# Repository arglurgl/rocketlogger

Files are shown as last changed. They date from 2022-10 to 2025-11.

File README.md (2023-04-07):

# rocketlogger
A data logger for water rockets

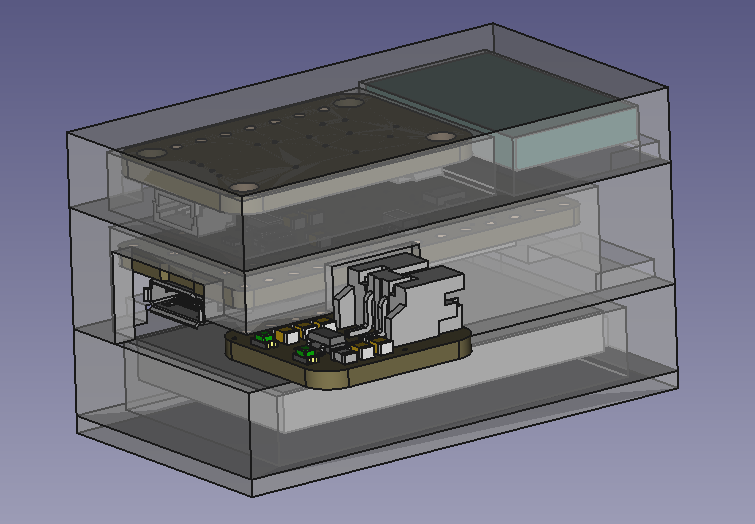
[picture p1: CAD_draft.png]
Draft Version


## Hardware
* Adafruit 4481 ItsyBitsy NRF52840
* Adafruit 2652 BMP280 STEMMA QT Altimeter and Pressure
* Generic Bosch BNO055 Acceleration and Attitude Breakout Board
* Adafruit 2124 LiPo Charger Backpack
* Generic 150 mAh LiPo Battery

## Planned Features
* Log altitude, acceleration, heading, ...
* Transfer data after landing via Bluetooth
* Data viewer with derived values like climb speed etc.
* Trigger parachute deployment
* Rocket recovery helper via sound and light
* (Speed logging from ground via audio (Doppler) and light (flashing and long exposure at night)

## First Time Setup
When running the code for the first time on a new board it will complain in the serial monitor about the filesystem missing. To format the flash, simply uncomment the line `format_flash();` in `setup()` and hit 'upload and monitor' in PlatformIO. Confirm the format in the serial monitor, and when done comment the format_flash line out again and re-upload the code to restart the board.

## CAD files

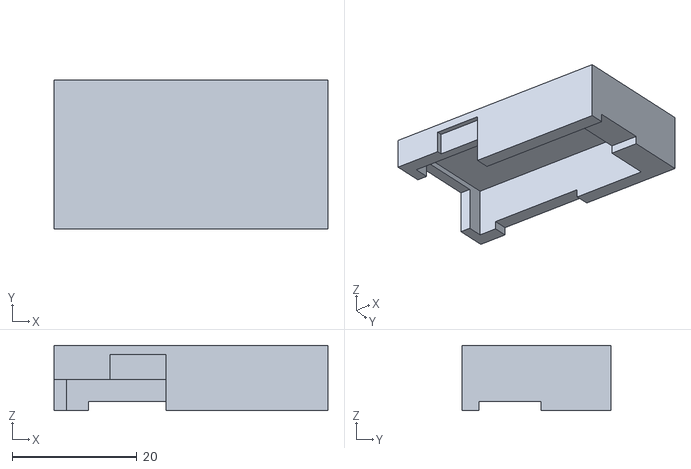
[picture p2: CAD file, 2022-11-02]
CAD/mainComp.stl
44.0 x 24.0 x 10.5

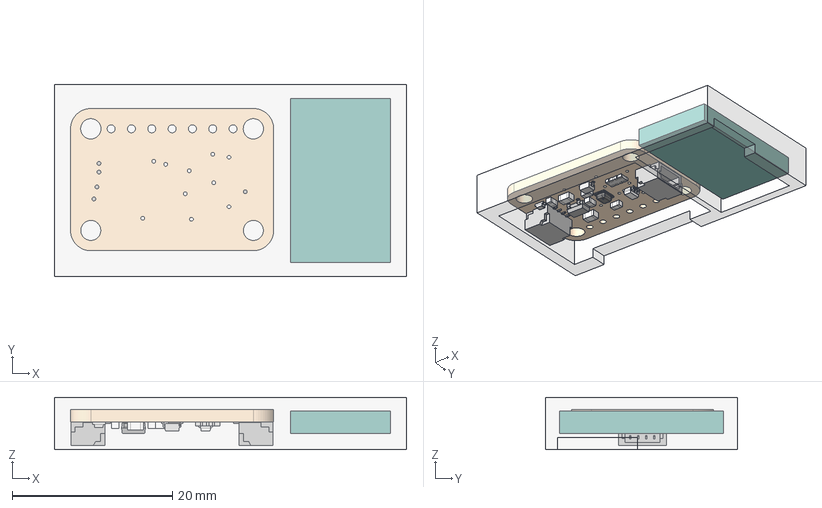
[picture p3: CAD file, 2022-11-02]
CAD/assembly.FCStd
44.0 x 24.0 x 6.50 mm
Board002
0805-NO008
0805-NO009
SOT23-007
0603-NO006
0603-NO007
0603-NO008
0603-NO009
RESPACK_4X0603
SOT363
JST_SH4
JST_SH005
CHIPLED_0603_NOOUTLINE
SOD-323
BMX280_COMBO
BNO055
alti+accel

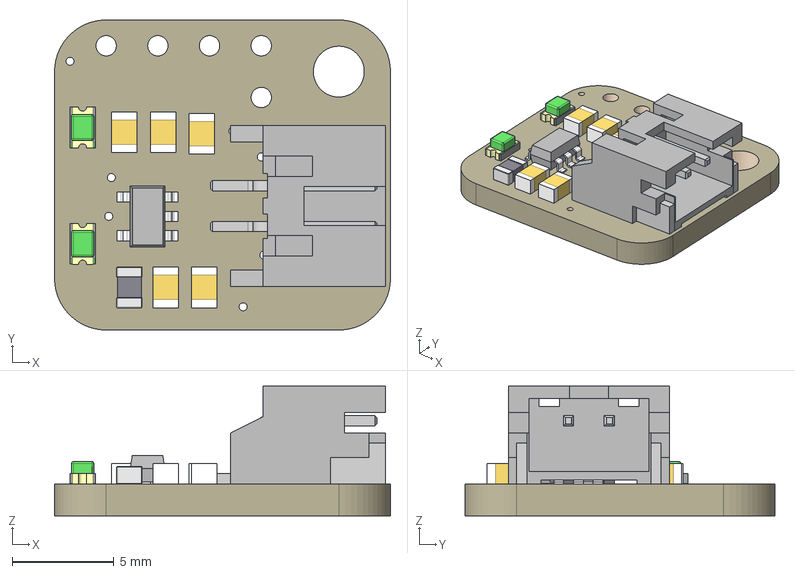
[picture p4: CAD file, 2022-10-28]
CAD/adafruit models/2124 Trinket Lipo Backpack.step
16.5 x 15.2 x 6.37 mm
Board
MCP73831T-2ACI/OT
GREEN x 2
2.5K x 5
JSTPH
10K\

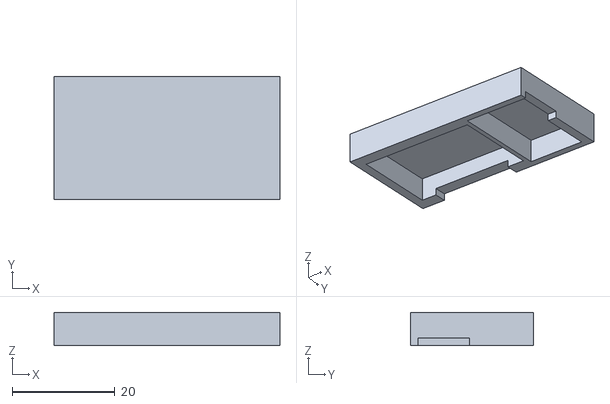
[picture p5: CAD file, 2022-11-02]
CAD/sensorComp.stl
44.0 x 24.0 x 6.50

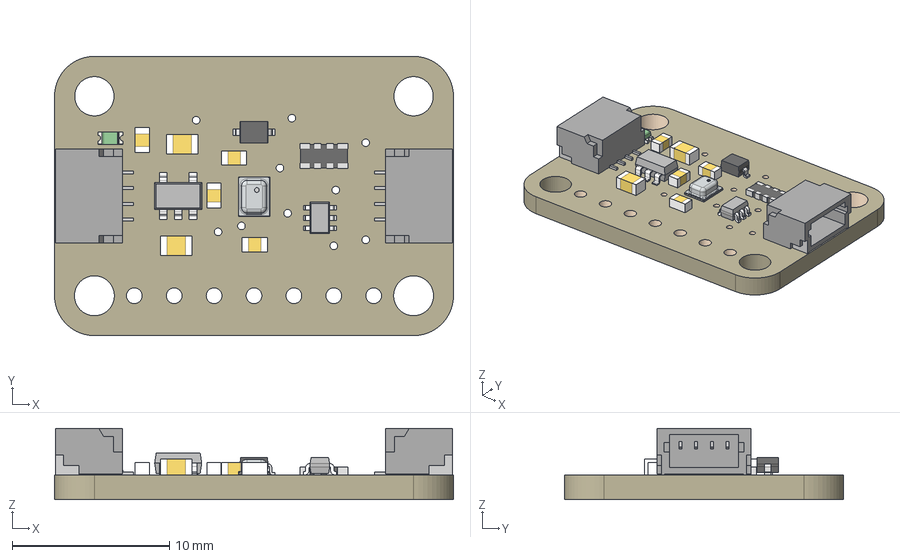
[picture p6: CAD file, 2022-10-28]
CAD/adafruit models/2652 BMP280 STEMMA QT.step
25.4 x 17.8 x 4.53 mm
Board
10uF x 2
AP2112K-3.3
10K x 4
10K_1
BSS138
STEMMA_I2C_QT x 2
GREEN
1N4148
BMX280_COMBO

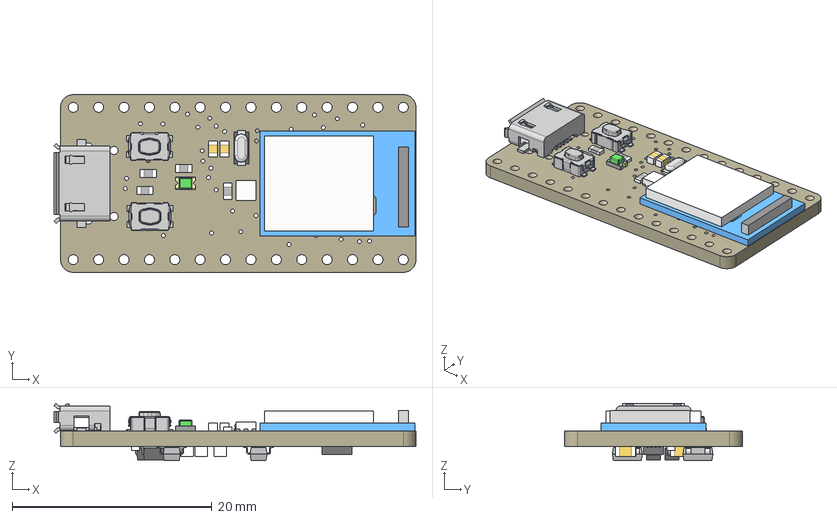
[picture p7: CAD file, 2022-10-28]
CAD/adafruit models/4481 ItsyBitsy nRF52840.step
36.2 x 17.8 x 5.74 mm
Board
KMR2 x 2
AP2112(3.3V)
4u20329
MBR120 x 2
RED
MDBT50
GD25Q16
10K x 6
10uF x 3
AP102-2020
22pF x 2
74HCT1G125DBV

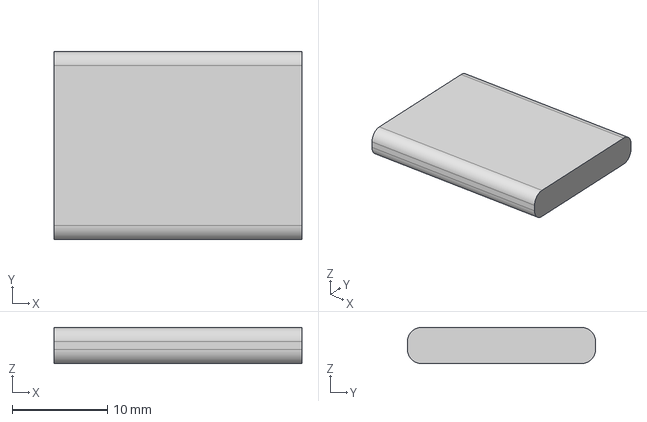
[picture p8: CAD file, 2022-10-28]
CAD/adafruit models/1317 150mAh Lipo Battery.step
26.0 x 19.8 x 3.80 mm

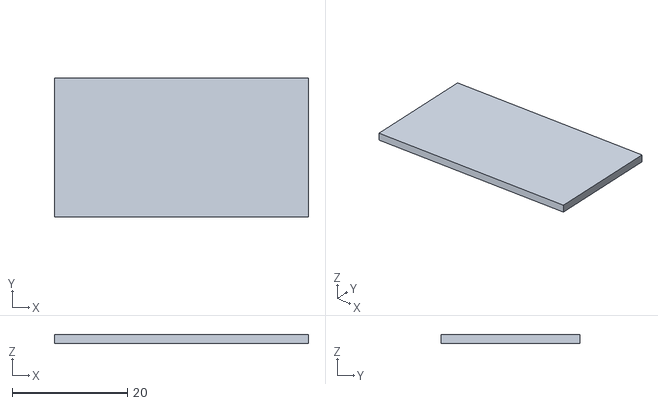
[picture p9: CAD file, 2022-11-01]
CAD/cover.stl
44.0 x 24.0 x 1.50

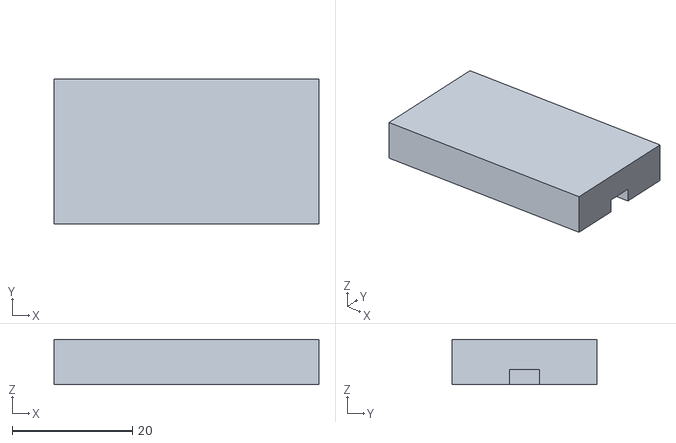
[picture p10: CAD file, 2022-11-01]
CAD/batteryComp.stl
44.0 x 24.0 x 7.50

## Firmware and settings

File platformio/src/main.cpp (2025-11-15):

/*********************************************************************
 This is an example for our nRF52 based Bluefruit LE modules

 Pick one up today in the adafruit shop!

 Adafruit invests time and resources providing this open source code,
 please support Adafruit and open-source hardware by purchasing
 products from Adafruit!

 MIT license, check LICENSE for more information
 All text above, and the splash screen below must be included in
 any redistribution
*********************************************************************/
#include <Arduino.h>
#include <SPI.h>
#include <Adafruit_Sensor.h>
#include <utility/imumaths.h>
#include <flash.h>
#include <bluetooth.h>
#include <pressure.h>
#include <orientation.h>
#include <led.h>
#include <flightstate.h>

#define INITIAL_REF_HEIGHT 50.0 // height to use in initial setup //TODO save in persistent memory

// New: flight logging / state machine constants and storage
#define MAX_SAMPLES 12000
#define SAMPLE_INTERVAL_MS 100        
#define LAUNCH_DELTA 1.0             // meters above armed reference to detect launch
#define LAND_ALT_THRESHOLD 0.3       // meters to consider landed
#define MIN_RECORD_TIME_MS 2000      // min recording time before landing is recognized

static FlightState flightState = STANDBY;

static size_t log_count = 0;
static unsigned long lastSampleMillis = 0;
static unsigned long recordingStartMillis = 0;
static float armed_ref_height = 0.0f;

// BLE packet buffer
//    READ_BUFSIZE            Size of the read buffer for incoming packets
#define READ_BUFSIZE                    (20)
uint8_t packetbuffer_receive[READ_BUFSIZE+1];

// Function prototypes
uint8_t readPacket(BLEUart *ble_uart, uint16_t timeout);
void startArming();
void startRecording();
void stopRecording();
void sampleIfNeeded();
void transferLog();
// New prototype for status send
void sendStatusViaBLE(BLEUart *bleuart);

// New: helper to parse remote_logger packets (expected: 0x00, 'T', sub)
static bool handleRemoteCommand(uint8_t *pkt, uint8_t len)
{
  if (len < 3) return false; // need at least 3 bytes
  // remote_logger sends: [0]=0x00, [1]='T', [2]=sub
  // be tolerant: require pkt[1]=='T'
  if (pkt[1] != 'T') return false;

  char sub = pkt[2];
  if (sub == 'A') // Arm
  {
    if (flightState == STANDBY)
      startArming();
    else
      Serial.println("Cannot arm: not in STANDBY");
  }
  else if (sub == 'T') // Transfer
  {
    if (flightState == STANDBY)
      transferLog();
    else
      Serial.println("Cannot transfer: must be in STANDBY");
  }
  else if (sub == 'S') // Stop / abort
  {
    stopRecording();
  }
  else if (sub == 'I') // Info / Status
  {
    // always allowed; send current state and sample count
    sendStatusViaBLE(&bleuart);
  }
  else
  {
    Serial.print("Unknown remote subcommand: ");
    Serial.println(sub);
    return false;
  }
  return true;
}

// Packet buffer
extern uint8_t packetbuffer_receive[];

// for testing BLE data stream
bool ble_stream = false;

void printBMP280Values()
{
  Serial.print(F("Temperature = "));
  Serial.print(pressureSensor.readTemperature());
  Serial.println(" *C");

  Serial.print(F("Pressure = "));
  Serial.print(pressureSensor.readPressure());
  Serial.println(" Pa");

  Serial.print(F("appr. relative height = "));
  float rel_height = relativeAltitude();
  Serial.print(rel_height, 1); /* Adjusted to local forecast! */
  Serial.println(" m");

  // LED for speed test
  if (rel_height > 0)
    rgbled.setPixelColor(0, 0, 64, 0);
  else
    rgbled.setPixelColor(0, 64, 0, 0);
  rgbled.show();

  Serial.println();
}

void sendSensorValues()
{
  sensors_event_t event;

  // get the sensor data
  orientationSensor.getEvent(&event, Adafruit_BNO055::VECTOR_GRAVITY);
  float temp = pressureSensor.readTemperature();
  float press = pressureSensor.readPressure();
  float rel_height = relativeAltitude();

  Serial.print("Gravity ");
  Serial.print("X: ");
  Serial.print(event.acceleration.x, 4);
  Serial.print("\tY: ");
  Serial.print(event.acceleration.y, 4);
  Serial.print("\tZ: ");
  Serial.print(event.acceleration.z, 4);
  Serial.println("");

  Serial.print(F("Temperature = "));
  Serial.print(temp);
  Serial.println(" *C");

  Serial.print(F("Pressure = "));
  Serial.print(press);
  Serial.println(" Pa");

  Serial.print(F("appr. relative height = "));
  Serial.print(rel_height, 1);
  Serial.println(" m");

}

void startArming()
{
  armed_ref_height = relativeAltitude();
  flightState = ARMED;
  Serial.print("State: ARMED (ref ");
  Serial.print(armed_ref_height, 3);
  Serial.println(" m)");
}

void startRecording()
{
  log_count = 0;
  recordingStartMillis = millis();
  lastSampleMillis = 0;
  // start fresh persistent log for this flight
  clearLog();
  flightState = RECORDING;
  Serial.println("Recording started");
}

void stopRecording()
{
  flightState = STANDBY;
  Serial.print("Recording stopped, samples: ");
  Serial.println(log_count);
}

void sampleIfNeeded()
{
  if (flightState != RECORDING)
    return;
  unsigned long now = millis();
  if ((now - lastSampleMillis) < SAMPLE_INTERVAL_MS)
    return;
  lastSampleMillis = now;
  float relh = relativeAltitude();
  if (log_count < MAX_SAMPLES)
  {
    float t = (now - recordingStartMillis) / 1000.0f; // seconds
    // append to persistent storage 
    appendLogSample(t, relh);
    log_count++;
  }
  // landing detection: returned near ground after some recording time
  if ((relh <= LAND_ALT_THRESHOLD) && ((now - recordingStartMillis) > MIN_RECORD_TIME_MS))
  {
    stopRecording();
  }
}

void transferLog()
{
  Serial.print("Transferring log via BLE, samples=");
  uint32_t persistent_count = getLogSampleCount();
  if (persistent_count > 0)
  {
    Serial.println(persistent_count);
    // transfer persistent log (preferred)
    transferLogViaBLE(&bleuart);
    Serial.println("Persistent transfer complete");
    return;
  }

  Serial.println(F("No data stored, returning..."));

}

// New: send status line via BLE in simple CSV text form:
// "STATUS,<STATE>,<SAMPLES>\n"
void sendStatusViaBLE(BLEUart *bleuart)
{
  if (!bleuart) return;

  const char *state_str = "UNKNOWN";
  if (flightState == STANDBY) state_str = "STANDBY";
  else if (flightState == ARMED) state_str = "ARMED";
  else if (flightState == RECORDING) state_str = "RECORDING";

  uint32_t samples = getLogSampleCount();

  char buf[64];
  int n = snprintf(buf, sizeof(buf), "STATUS,%s,%lu\n", state_str, (unsigned long)samples);
  if (n <= 0) return;

  // Debug print to serial
  Serial.print(F("[BLE STATUS TX] "));
  Serial.write((const uint8_t*)buf, (size_t)n);
  Serial.println();

  // Send via BLE UART. 
  bleuart->write((const uint8_t*)buf, (size_t)n);
  bleuart->flushTXD();

  // small delay to allow BLE stack to schedule notification
  delay(20);
}

void setup(void)
{
  Serial.begin(115200);

  // for nrf52840 with native usb, wait for Serial connection unless timeout happens
  uint8_t tries = 0;
  while ((!Serial) && (tries < 200))
  {
    delay(10);
    tries++;
  }
  // flush any remaining incoming data from e.g. upload process
  while (Serial.available() > 0)
    Serial.read();

  Serial.println("Starting setup");

  Serial.print(F("  RGB LED..."));
  setupLED();
  Serial.println(F("OK"));

  Serial.print(F("  Flash/filesystem..."));
  // uncomment this next line and follow instructions on monitor to format a new device's flash, this will erase all data!
  // format_flash();
  setupFlash();
  Serial.println(F("OK"));
  // test_fatfs(); //TODO for testing, remove

  Serial.print(F("  Bluetooth..."));
  setupBluetooth();
  Serial.println(F("OK"));

  Serial.print(F("  Pressure sensor..."));
  setupPressureSensor(INITIAL_REF_HEIGHT);
  Serial.println(F("OK"));

  Serial.print(F("  Orientation sensor..."));
  setupOrientationSensor();
  Serial.println(F("OK"));

  Serial.println("Setup done");
}

void loop(void)
{ 
  while (true){

    // Update LED based on flight state
    updateLED(flightState);
    // State machine: check sensors and sample if needed
    // State-specific behavior
    if (flightState == ARMED)
    {
      // detect launch by altitude increase above armed reference
      float rel_height = relativeAltitude();
      if ((rel_height - armed_ref_height) > LAUNCH_DELTA)
      {
        startRecording();
      }
    }
    else if (flightState == RECORDING)
    {
      sampleIfNeeded();
    }


    // Wait for new BLE data to arrive
    uint8_t len = readPacket(&bleuart, 10); // was 500 before speed test
    if (len >= 3){
      // Try to handle as remote_logger packet
      handleRemoteCommand(packetbuffer_receive, len);
    }

  }  
}

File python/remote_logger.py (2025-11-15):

"""
Simple BLE remote for RocketLogger.
Requires: bleak (pip install bleak)

Usage examples:
  python remote_logger.py --addr AA:BB:CC:DD:EE:FF --transfer --out flight.csv
  python remote_logger.py --addr AA:BB:CC:DD:EE:FF --arm

Protocol (matches device expectations):
 - Commands are sent as three-byte packets: b'\x00' + b'T' + sub
   where sub is one of:
     b'A' = Arm
     b'T' = Transfer log
     b'S' = Stop/abort
 - Device will stream text:
     "LOG_START\n"
     "time_seconds,altitude_m\n"  (one per sample)
     "LOG_END\n"
"""
import argparse
import asyncio
from bleak import BleakClient, BleakScanner

# Nordic UART Service (common Adafruit / UART-over-BLE)
UART_SERVICE = "6E400001-B5A3-F393-E0A9-E50E24DCCA9E"
UART_RX_CHAR = "6E400002-B5A3-F393-E0A9-E50E24DCCA9E"  # write here
UART_TX_CHAR = "6E400003-B5A3-F393-E0A9-E50E24DCCA9E"  # notify here

async def run(addr, do_arm, do_transfer, do_stop, do_status, outfile):
    if not addr:
        print("Scanning for RocketLogger device...")
        devices = await BleakScanner.discover(timeout=5.0)
        if not devices:
            print("No BLE devices found")
            return
        
        # Find first device named "rocketlogger"
        rocketlogger = next((d for d in devices if d.name and "rocketlogger" in d.name.lower()), None)
        if not rocketlogger:
            print("RocketLogger device not found!")
            print("Available devices:")
            for d in devices:
                print(f"  - {d.name or '(unnamed)'} ({d.address})")
            return
        
        addr = rocketlogger.address
        print(f"Found RocketLogger: {rocketlogger.name} ({addr})")

    received = []
    in_log = False
    buffer = ""                       # buffer for partial lines
    transfer_done = asyncio.Event()   # signalled when LOG_END seen

    # status reply state
    status_done = asyncio.Event()
    status_line = None

    def handle_notify(sender, data):
        nonlocal in_log, received, buffer, transfer_done, status_done, status_line
        text = data.decode('utf-8', errors='ignore')
        buffer += text

        # debug
        #print(f"[raw] received {len(text)} bytes: [{text}], buffer now: {repr(buffer)}")

        # extract full lines from the buffer
        while '\n' in buffer:
            line, buffer = buffer.split('\n', 1)
            l = line.rstrip('\r')

            # status line (single-line reply)
            if l.startswith("STATUS,"):
                status_line = l
                print("[remote] STATUS reply:", l)
                status_done.set()
                continue

            if l == "LOG_START":
                in_log = True
                received = []
                transfer_done.clear()
                print("[remote] LOG_START")
            elif l == "LOG_END":
                in_log = False
                print("[remote] LOG_END, {} lines".format(len(received)))
                if outfile:
                    with open(outfile, "w") as fh:
                        fh.write("\n".join(received) + ("\n" if len(received) > 0 else ""))
                    print("[remote] Written to", outfile)
                transfer_done.set()
            else:
                if in_log:
                    received.append(l)
                    print("[log] ", l)

    async with BleakClient(addr) as client:
        svcs = client.services
        if UART_RX_CHAR not in svcs.characteristics and UART_TX_CHAR not in svcs.characteristics:
            # Some stacks require lower-case UUIDs or discovery; still continue
            pass

        # Register notify handler BEFORE sending any commands
        await client.start_notify(UART_TX_CHAR, handle_notify)

        # Helper to send command: three bytes: 0x00' + b'T' + sub
        async def send_cmd(sub_char: bytes):
            pkt = b'\x00' + b'T' + sub_char
            await client.write_gatt_char(UART_RX_CHAR, pkt)
            print("[remote] Sent command:", pkt)

        try:
            if do_arm:
                await send_cmd(b'A')
            if do_stop:
                await send_cmd(b'S')
            if do_transfer:
                if outfile:
                    open(outfile, "w").close()
                transfer_done.clear()
                await send_cmd(b'T')
                try:
                    await asyncio.wait_for(transfer_done.wait(), None)
                except asyncio.TimeoutError:
                    print("[remote] Transfer timed out waiting for samples")
                    print("[remote] Received {} lines before timeout".format(len(received)))

            if do_status:
                # request status and wait for single-line reply
                status_done.clear()
                status_line = None
                await send_cmd(b'I')
                try:
                    await asyncio.wait_for(status_done.wait(), timeout=5.0)
                except asyncio.TimeoutError:
                    print("[remote] Status request timed out")
                else:
                    print("[remote] Status:", status_line)

            await asyncio.sleep(0.5)
        finally:
            await asyncio.sleep(0.1)
            await client.stop_notify(UART_TX_CHAR)

def parse_args():
    p = argparse.ArgumentParser()
    p.add_argument("--addr", help="BLE device address (optional, will scan if omitted)")
    p.add_argument("--arm", action="store_true", help="Send ARM command")
    p.add_argument("--transfer", action="store_true", help="Request log transfer")
    p.add_argument("--stop", action="store_true", help="Send STOP/abort")
    p.add_argument("--status", action="store_true", help="Request device status")
    p.add_argument("--out", dest="outfile", default="flight.csv", help="Output CSV file for log")
    return p.parse_args()

def main():
    args = parse_args()
    asyncio.run(run(args.addr, args.arm, args.transfer, args.stop, args.status, args.outfile))

if __name__ == "__main__":
    main()

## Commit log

2022-10-16 RGB LED control test via bluefruit LE connect
2022-10-16 add python ble uart test
2022-10-17 add pressure sensor test
2022-10-17 add pressure calibration and speed test
2022-10-18 test BNO055 sensor
2022-10-19 print gravity vector
2022-10-20 test multiple sensor stream
2022-10-28 add first CAD parts
    [1317 150mAh Lipo Battery.step, 2124 Trinket Lipo Backpack.step, 2652 BMP280 STEMMA QT.step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]
2022-11-01 draft version of component holder
    [assembly.FCStd]
2022-11-01 add stl of draft holder
    [assembly.FCStd, batteryComp.stl, cover.stl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]
2022-11-02 adjust fit of mainboard and sensors
    [assembly.FCStd, mainComp.stl, sensorComp.stl]
2023-04-09 refactor pressure sensor
2023-04-10 refactor orientation sensor
2023-04-10 refactor RGB LED
2023-08-05 add rudimentary list and print file commands
2025-11-15 fix typo, adjust sample interval
    [flash.cpp, main.cpp]
2025-11-15 add state LED color
